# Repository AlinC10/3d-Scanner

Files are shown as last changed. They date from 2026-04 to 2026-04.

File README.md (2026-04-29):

# 3D Scanner Project

## How it started

This is a project created for the **Electrical Machines and Drives** university course. The main criteria for the project was to use an electrical motor.

## About the project

This is 3D scanning system built using an IR distance sensor and 2 stepper motors. The project transform the geometry of real objects into a Point Cloud and generates a 3D surface (Mesh), ready for 3D printing.

## Features

* **GUI**: An app written in Python (Tkinter library) with support for keyboard navigation, real-time log updates via Threading and automatic COM port management.
* **Automatic Surface Reconstruction**: Transform `.xyz` data into a 3d Model (`.obj`) using PyMeshLab
* **2-Axis Kinematics**: Control of the rotating turntable and the elevator using stepper motors and mechanical endstops.

[For information about software side of the project click here](./app_code/README.md)

## Hardware

### Bill of Materials

* **Microcontroller:** 1x Arduino Uno
* **Motors:** 2x 5V 28BYJ-48 Stepper Motors + Drivers
* **Sensor:** 1x Sharp GP2Y0A41SK0F (4-30 cm) IR sensor
* **Power Supply:** 1x 9v, 0.55A Power Supply (for motors)
* **Other Components for Arduino:**
  * 2x Mechanical Endstop (for bottom and upper parts of the threaded rod)
  * 1x Electrical Switch
  * Resistors (2x 100k, 10k)
  * Breadboard
* **Other components:**
  * 1x M8 Threaded Rod (for Z-axis)
  * 3x Hex Nuts
  * 2x Round Bars
  * 2x Low Pressure Ferrule
  * 1x Aluminium Flexible Coupling 5mm * 8mm (between motor's rod and M8 threaded rod)
  * Turntable (from a pick-up)
  * 2x Steel Flat Bar

### Components connections

* Sharp GP2Y0A41SK0F (4-30 cm) IR sensor: A0, GND, 5V
* Motors:
  * Turntable: 8-11 digital, breadboard +/-
  * Threaded Rod: 4-7 digital, breadboard +/-
* Mechanical Endstops:
  * Upper: from NO - breadboard - digital 3, breadboard -
  * Bottom: from NO - breadboard - digital 2, breadboard -
* Power Supply: + - breadboard + - voltage divider (110k, 100k) - digital 1, - to Electrical Switch to breadboard -

### [TinkerCad project design](https://www.tinkercad.com/things/5zCmhctaVLh-3d-scanner?sharecode=bmv8x4omlR0UC9AtyNq_ofs1a5cjaq0OV72FfIZm1b8)

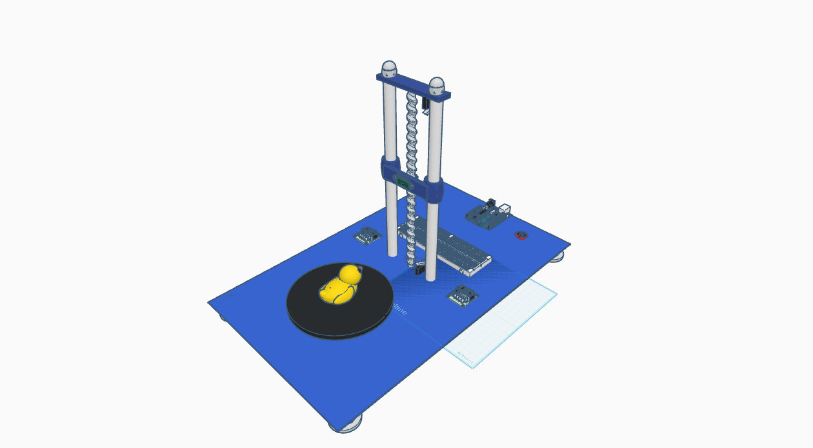
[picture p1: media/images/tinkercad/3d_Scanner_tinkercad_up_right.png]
3d scanner upper right

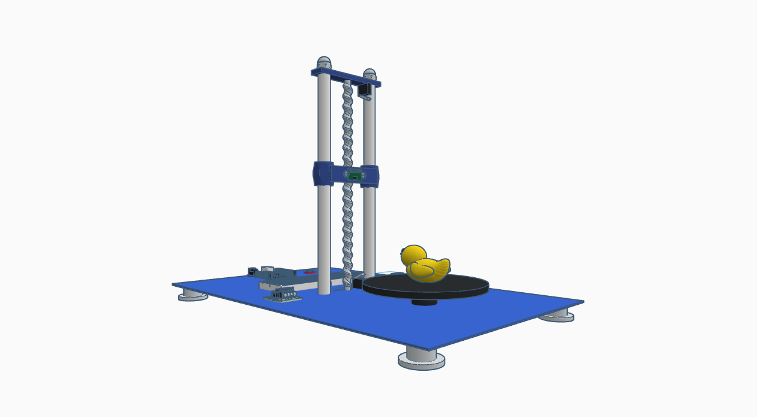
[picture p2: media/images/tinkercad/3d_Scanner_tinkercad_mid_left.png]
3d scanner mid left

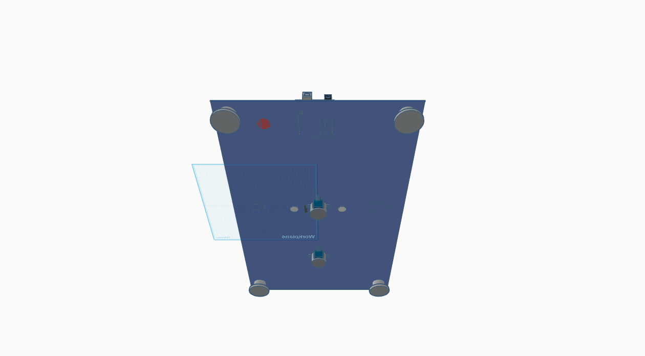
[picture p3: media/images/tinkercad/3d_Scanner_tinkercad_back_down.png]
3d scanner back down


### Real-life images of the scanner

### Future hardware updates

* change IR sensor with a camera and get coordinates from images
* change M8 rod with a T8 Threaded rod for faster movement on it

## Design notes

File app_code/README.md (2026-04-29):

# 3D Scanner Project

## Software

The logic of the system was implemented using C++ code (in Arduino IDE) and Python with multiple libraries.

*Note:* The GUI is currently in Romanian.

### Arduino

Arduino is responsible for how the scanner moves, scans the object and calculates the coordinates. The logic was created using OOP principles, creating different classes for different hardware components and handling their behavior inside the methods.

The classes created are:

* IR_Sensor:
  * getDistance(): was created using `SharpIR` library (by Giuseppe Masino) as a reference point. The problem with the already implemented one was that it only calculated the distance as an `int`, which was not useful for a system that tries to catch as many details as it can from an object. My implementation returns a `float` number, which represents the distance from the sensor to the object in millimeters. For a better value for the distance, the method makes multiple readings (10 by default) and returns the average distance.

* Endstop: checks if sensor reached bottom/upper part of the threaded rod
* Switch: checks if the power supply\switch is on
* Motor:
  * halfStepForward/Backwards(), fullStepForward/Backwards(): methods used to rotate motors forward/backwards in 2048 (with full step for threaded rod) or 4906 (with half step for turntable) depending on the needed precision.

Arduino code *only executes* if it receives a command from Python script, so it can't scan without Python script opened.

Variables used in the scanning process can be changed via Python script, in the `Opțiuni` menu from `Meniul Principal` without re-uploading the code (the settings changed will return to their values from Arduino code on the next launch) or via Arduino IDE (which means that the code needs to be re-uploaded).

### Python

The Python script acts as the "brain" of the operation on the PC side. It provides a Graphical User Interface (GUI), handles real-time communication with the microcontroller, and performs the complex 3D surface reconstruction. The entire logic is encapsulated in the ScannerApp class.

#### Features:
* **Serial Communication:** Utilizing the `pyserial` library (operating at a baud rate of `115200`), the script reads the incoming coordinates line by line and displays them in real-time. It also sends commands (START, STOP) and can dynamically update Arduino variables (like the number of measurements or sensor readings) without requiring the Arduino code to be recompiled or re-uploaded.
* **Data Management:** The raw coordinates are kept in memory and safely exported as an .xyz Point Cloud file. The script uses the pathlib library to automatically manage directories and save scans in dedicated folders based on user input.
* **Automated 3D Surface Reconstruction:** Once the scan is complete, the pymeshlab library is used to transform the raw .xyz points into a solid, 3D-printable .obj mesh

### How to run it

1. Setup Arduino

    1. Open `.\app_code\main\main.ino` in Arduino IDE.
    2. Check pins mapping for all hardware components.
    3. Upload code to Arduino.

2. Setup Python (3.11)
    1. Open terminal in `.\app_code\python`.
    2. Run `python -m venv .venv`
    3. Activate environment `.venv\Scripts\activate`
    4. Install libraries: `pip install -r requirements.txt`.
  
3. Install `MeshLab` to view the scanned object (optional, you can upload the `.xyz` in another app)

4. Connect Arduino, plug in the power supply and turn on the switch.

5. Run `3dScanner.exe` from `.\` or from terminal `python .\app_code\python\main.py`.

6. Press `Incepe scanarea` to start scanning.

7. After the scanning process, complete the name of the file in the pop-up window. For example, you can name the file `duck`, `my_favorite_duck`.

8. Click `Vizualizare obiect` to see the scanned object or choose `Meniu Principal` to go to the Main Menu. The file with scanned coordinates can be found in `.\scanari\your_object_name\your_object_name.xyz`.

### Future software updates

* create issues to better manage updates
* auto-search for arduino COM and baud-rate
* implement a ML algorithm to correct object coordinates
* migrate UI from Python Tkinter to a web based interface
* create a backend with python for sending information to the javascript frontend

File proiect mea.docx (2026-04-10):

Perfectă decizie! Trecerea de la un CD la o placă din MDF (de 6 mm sau 8 mm grosime) sau o foaie de plastic rigid va face scannerul mult mai stabil, va elimina vibrațiile și îți va permite să scanezi obiecte mai grele.

Pentru a-ți face viața mai ușoară, am împărțit "coșul de cumpărături" în două categorii: ce iei de la magazinele de electronică (cum ar fi Optimus Digital, Clește.ro, RoboFun etc.) și ce iei de la magazinele de bricolaj (Dedeman, Hornbach, Leroy Merlin).

Presupun că ai deja placa Arduino Uno și cablul USB.

1. Electronice (Magazine de specialitate / Roboți)

- 1x Senzor de distanță ToF VL53L0X (~25 - 35 RON).
- 2x Motoare pas cu pas 28BYJ-48 (5V) cu driver ULN2003 (~15 RON bucata -> 30 RON total). Atenție să iei varianta de 5V, nu cea de 12V.
- 1x Set fire Dupont (Tată-Mamă și Mamă-Mamă) (~10 RON). Ai nevoie de ele pentru a conecta pinii plăcuțelor direct la Arduino și între ele.
- 1x Breadboard (placă de teste) mic sau mediu (~10 RON). Te va ajuta enorm să distribui alimentarea de 5V către ambele motoare și senzor.
- 1x Microîntrerupător (Limitator de cursă / Endstop) (~3 - 5 RON). Un buton mic pe care îl vei pune la baza tijei pentru a-i spune senzorului unde este punctul "zero".
- (Opțional, dar recomandat) 1x Cuplaj flexibil aluminiu (5mm la 5mm sau 5mm la 6mm) (~15 RON). Te va ajuta să prinzi perfect axul motorului de tija filetată. Axul motorului 28BYJ-48 are 5mm. Dacă iei o tijă filetată de 5mm, iei cuplaj 5mm-5mm.

Total estimat electronice: ~80 - 95 RON

2. Mecanică și Bricolaj (Dedeman / Hornbach etc.)

- 1x Tijă filetată M5 sau M6 (~5 - 10 RON). Se vinde la bucăți de 1 metru. (M5 înseamnă grosime de 5 mm).
- 1x Pungă mică piulițe (M5 sau M6, în funcție de tijă) + șaibe (~5 RON).
- 1x Tijă netedă pentru ghidaj (țeavă subțire de aluminiu sau oțel neted de 6mm sau 8mm) (~10 RON). Tot la profilul de 1 metru o găsești. Trebuie să fie perfect dreaptă.
- 1x Placă MDF (grosime 6mm sau 8mm) (~15 - 20 RON). De obicei găsești resturi sau plăci mici (ex: 60x60 cm). Din ea vei tăia baza, peretele vertical (în forma de "L") și vei decupa cercul pentru platan.
- 1x Set colțare metalice mici (în formă de L) + holzșuruburi scurte (~10 RON). Pentru a prinde peretele vertical de baza orizontală la un unghi perfect de 90 de grade.
- (Opțional) Bile de transfer (Role / Rulmenți de mobilă mici) (~15 RON). Le prinzi pe bază, sub platanul de MDF, ca platanul să alunece pe ele. Asta ia toată greutatea de pe axul firav al motorului.

Total estimat bricolaj: ~60 - 70 RON

Sursa de alimentare (Improvizație acasă)

Pentru a alimenta motoarele, NU folosi portul USB de la PC prin Arduino. Caută prin casă un încărcător vechi de telefon care nu îți mai trebuie (dar să aibă minim 1.5 Amperi sau 2A scriși pe el). Îi vei tăia mufa, vei dezizola firele roșu (+) și negru (-) și le vei folosi pentru a aduce curent pe breadboard.

Cost total estimat al proiectului: Undeva la 150 RON, dar vei avea un scanner stabil, de o calitate mult superioară variantelor din carton sau cu senzor ultrasonic.

Ai prefera ca următorul pas să fie realizarea schemei de conectare (cum legăm firele între componente și Arduino) sau vrei să începem să scriem codul de bază pentru teste?

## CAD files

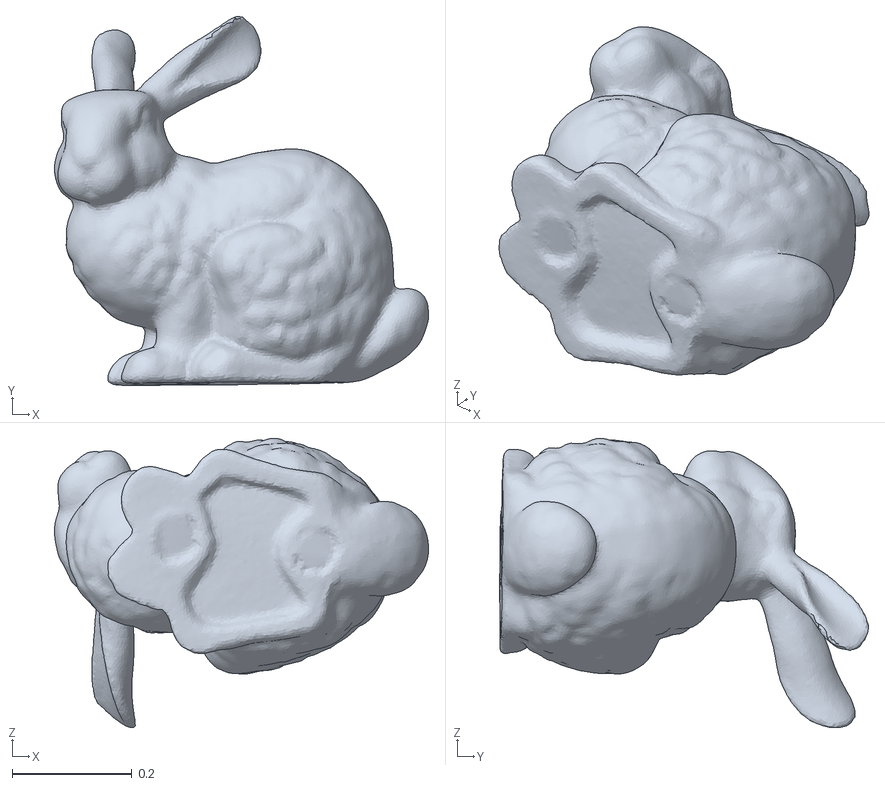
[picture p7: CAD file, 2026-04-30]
3d_Scanner_app/_internal/pymeshlab/tests/sample_meshes/bunny.obj
0.624 x 0.615 x 0.482

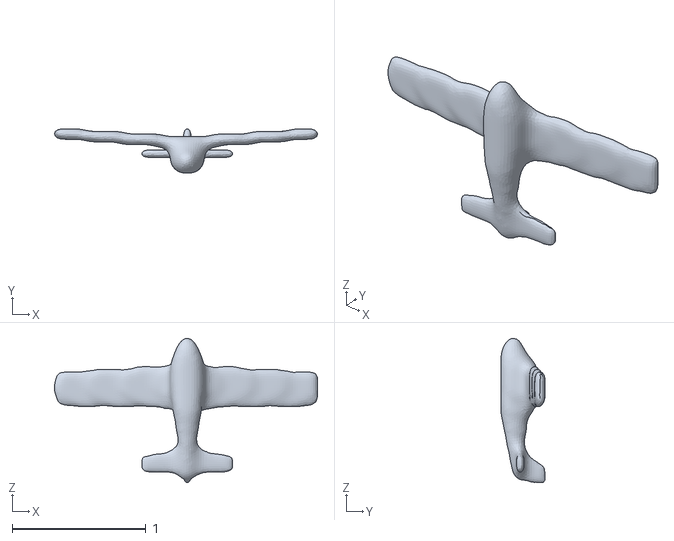
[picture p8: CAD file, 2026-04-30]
3d_Scanner_app/_internal/pymeshlab/tests/sample_meshes/colored_airplane.ply
1.96 x 0.331 x 1.08

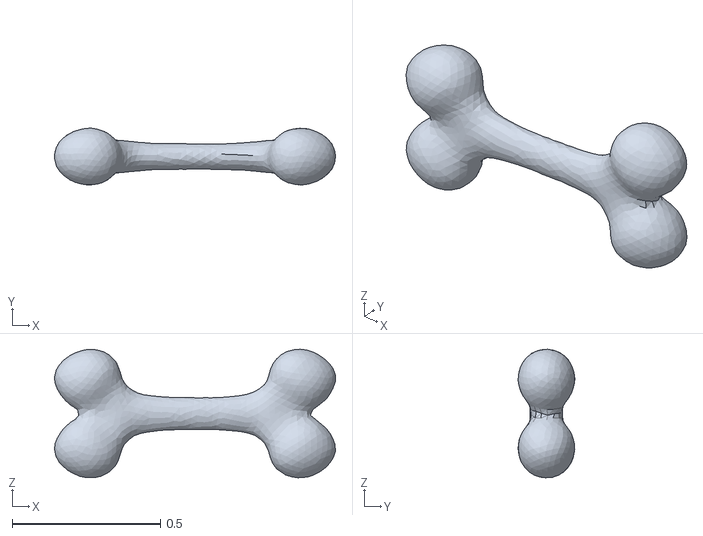
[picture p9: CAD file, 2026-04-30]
3d_Scanner_app/_internal/pymeshlab/tests/sample_meshes/bone.ply
0.949 x 0.192 x 0.435

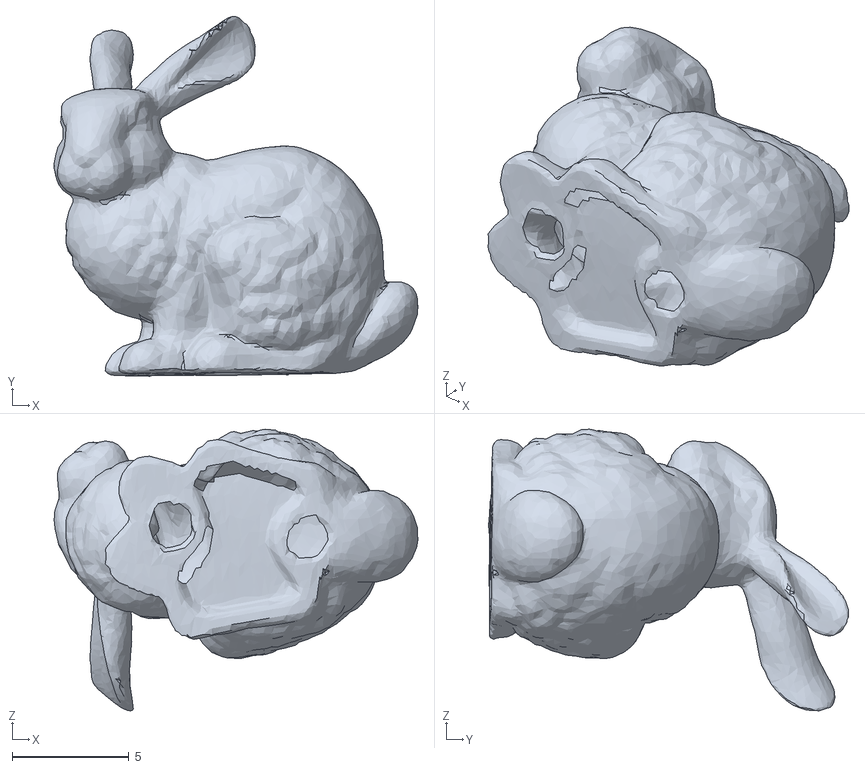
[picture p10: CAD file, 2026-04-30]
3d_Scanner_app/_internal/pymeshlab/tests/sample_meshes/bunny10k_textured.obj
15.6 x 15.4 x 12.1

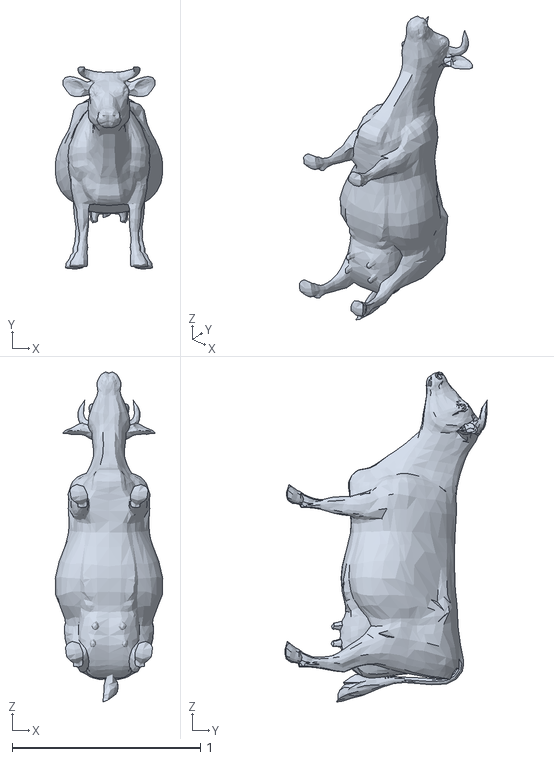
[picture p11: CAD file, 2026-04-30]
3d_Scanner_app/_internal/pymeshlab/tests/sample_meshes/cow.obj
0.572 x 1.08 x 1.76

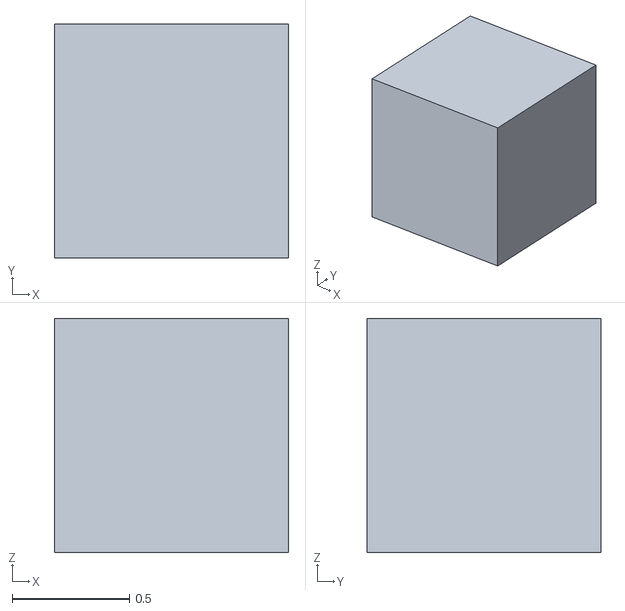
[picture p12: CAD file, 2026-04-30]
3d_Scanner_app/_internal/pymeshlab/tests/sample_meshes/cube.obj
1.00 x 1.00 x 1.00

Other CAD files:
3d_Scanner_app/_internal/pymeshlab/tests/sample_meshes/airplane.obj

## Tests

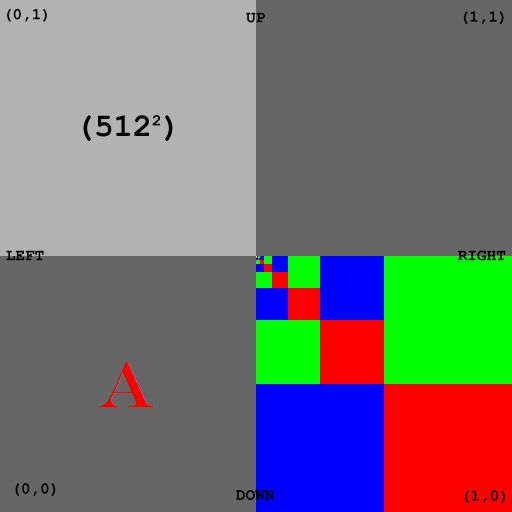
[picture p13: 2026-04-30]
3d_Scanner_app/_internal/pymeshlab/tests/sample_meshes/TextureDouble_A.png

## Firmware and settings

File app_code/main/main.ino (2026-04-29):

#include "motor.h"
#include "endstop.h"
#include "switch.h"
#include "IR_Senzor.h"
#include "scanner_functions.h"
#include <Wire.h>

#define M8_THREAD_STEP_MM 1.25
#define DISTANCE_TO_CENTER_MM 110.0
#define DISTANCE_TO_END_MM 240.0

Motor zMotor(Z_MOTOR_OUTPUT1, Z_MOTOR_OUTPUT2, Z_MOTOR_OUTPUT3, Z_MOTOR_OUTPUT4, ROTATION_STEPS_Z_MOTOR);
Motor turntableMotor(TURNTABLE_MOTOR_OUTPUT1, TURNTABLE_MOTOR_OUTPUT2, TURNTABLE_MOTOR_OUTPUT3, TURNTABLE_MOTOR_OUTPUT4, ROTATION_STEPS_TURNTABLE_MOTOR);

Endstop upperEndstop(UPPER_ENDSTOP_INPUT);
Endstop bottomEndstop(BOTTOM_ENDSTOP_INPUT);

Switch chargerSwitch(SWITCH_PIN);

IR_Senzor sensor(SENZOR_PIN);
long currentLevel = 0;

void setup() {
  Serial.begin(115200);

  // setup components pin
  zMotor.pinSetup();
  turntableMotor.pinSetup();

  upperEndstop.pinSetup();
  bottomEndstop.pinSetup();

  chargerSwitch.pinSetup();
}

void setupScanner() {
  Serial << "Start\n";

  if (!chargerSwitch.isOn()) {
    Serial << "Alimentare motoare oprita\n";

    // wait to turn on charger
    while (!chargerSwitch.isOn()) {
      delay(5000);
    }
  }

  if (!bottomEndstop.reachRodLimit()) {
    Serial << "Se ajusteaza inaltimea senzorului\n";

    // get IR sensor at the bottom of the threaded rod
    while (!bottomEndstop.reachRodLimit()) {
      zMotor.fullStepBackward();
    }
  }

    delay(500);

  for (int j = 0; j < zMotor.getRotationSteps(); j++) {
    zMotor.fullStepForward();
  }

  zMotor.stop();
  delay(2000);
}

void scanning() {
  while (true) {
    // variable used to automate stop scanner in case it finished object scanning
    bool hasScanned = false;

    Serial << "\n\nNivelul curent: " << currentLevel << "\n";

    if (checkStoppingConditions(upperEndstop.reachRodLimit(), zMotor, turntableMotor))
      return;

    const int stepsBetweenMeasurements = turntableMotor.stepsBetweenMeasurements();

    for (int i = 0; i < MEASUREMENTS_PER_ROTATION; i++) {

      for (int j = 0; j < stepsBetweenMeasurements / 8; j++) {
        turntableMotor.halfStepForward();
      }

      if (checkStoppingConditions(upperEndstop.reachRodLimit(), zMotor, turntableMotor))
        return;

      delay(100);

      float const distance = sensor.getDistance();

      turntableMotor.stop();
      if (distance > 40.0 && distance < DISTANCE_TO_CENTER_MM) {
        const float objRadius = DISTANCE_TO_CENTER_MM - distance;

        if (objRadius > 2.0) {
          float currentAngle = (360.0 / MEASUREMENTS_PER_ROTATION) * i;
          currentAngle *= (PI / 180.0);

          const float xPos = objRadius * cos(currentAngle);
          const float yPos = objRadius * sin(currentAngle);
          // const float zPos = (currentLevel * zMotor.getRotationSteps() / 2 * 4.0 * M8_THREAD_STEP_MM) / zMotor.getRotationSteps();
          const float zPos = currentLevel * 2 * M8_THREAD_STEP_MM;  // reduced form
          Serial << xPos << " " << yPos << " " << zPos << "\n";

          // create object base surface
          if (currentLevel == 0) {
            Serial << xPos * 0.75 << " " << yPos * 0.75 << " 0.0\n";
            Serial << xPos * 0.50 << " " << yPos * 0.50 << " 0.0\n";
            Serial << xPos * 0.25 << " " << yPos * 0.25 << " 0.0\n";
            Serial << "0.0 0.0 0.0\n";
          }

          hasScanned = true;
        }
      }
    }

    for (int j = 0; j < zMotor.getRotationSteps() / 2; j++) {
      if (checkStoppingConditions(upperEndstop.reachRodLimit(), zMotor, turntableMotor))
        return;
      zMotor.fullStepForward();
    }
    currentLevel++;
    zMotor.stop();

    if (checkStoppingConditions(!hasScanned, zMotor, turntableMotor))
      return;
  }
}

void readSerial() {
  // wait for user to select start scanning option
  // answer it's received by python and send through the serial to arduino
  if (Serial.available() > 0) {
    const String pythonCommand = Serial.readStringUntil("\n");
    pythonCommand.trim();

    // start scanning
    if (pythonCommand == "START") {
      setupScanner();
      scanning();
    }

    // command to stop scanning
    else if (pythonCommand == "STOP") {
      return;
    }

    // command to change variables values
    else {
      const int separatorIndex = pythonCommand.indexOf(":");

      if(separatorIndex != -1) {
        const String varName = pythonCommand.substring(0, separatorIndex);

        const int varValue = pythonCommand.substring(separatorIndex + 1).toInt();

        if (varName == "MEASSUREMENTS")
          MEASUREMENTS_PER_ROTATION = varValue;

        if (varName == "READINGS")
          readings = varValue;
      }
    }
  }
}

// run loop while arduino is turn on
void loop() {
  readSerial();
  delay(1000);
}

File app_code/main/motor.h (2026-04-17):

#pragma once
#include "Arduino.h"

#define Z_MOTOR_OUTPUT1 7
#define Z_MOTOR_OUTPUT2 6
#define Z_MOTOR_OUTPUT3 5
#define Z_MOTOR_OUTPUT4 4
#define ROTATION_STEPS_Z_MOTOR 2048

#define TURNTABLE_MOTOR_OUTPUT1 11
#define TURNTABLE_MOTOR_OUTPUT2 10
#define TURNTABLE_MOTOR_OUTPUT3 9
#define TURNTABLE_MOTOR_OUTPUT4 8
#define ROTATION_STEPS_TURNTABLE_MOTOR 4096

int MEASUREMENTS_PER_ROTATION = 64; // can be change by user through python script

class Motor {
private:
  int output1;
  int output2;
  int output3;
  int output4;
  int rotationSteps; // how many steps it take on a rotation
  static const int DELAY = 2;

public:
  Motor(int output1, int output2, int output3, int output4, int rotationSteps) {
    this->output1 = output1;
    this->output2 = output2;
    this->output3 = output3;
    this->output4 = output4;
    this->rotationSteps = rotationSteps;
  }

  void pinSetup() {
    pinMode(this->output1, OUTPUT);
    pinMode(this->output2, OUTPUT);
    pinMode(this->output3, OUTPUT);
    pinMode(this->output4, OUTPUT);
  }

  int stepsBetweenMeasurements() {
    return this->rotationSteps / MEASUREMENTS_PER_ROTATION;
  }

  int getRotationSteps() const {
    return this->rotationSteps;
  }

  void fullStepRotation(int output1, int output2, int output3, int output4) {
    digitalWrite(output1, HIGH);
    digitalWrite(output2, HIGH);
    digitalWrite(output3, LOW);
    digitalWrite(output4, LOW);
    delay(DELAY);
  }

  void halfStepRotation(int output1, int output2, int output3, int output4) {
    digitalWrite(output1, HIGH);
    digitalWrite(output2, LOW);
    digitalWrite(output3, LOW);
    digitalWrite(output4, LOW);
    delay(DELAY);
  }

  void fullStepForward() {
    this->fullStepRotation(this->output1, this->output2, this->output3, this->output4);
    this->fullStepRotation(this->output2, this->output3, this->output1, this->output4);
    this->fullStepRotation(this->output3, this->output4, this->output1, this->output2);
    this->fullStepRotation(this->output1, this->output4, this->output2, this->output3);
  }

  void fullStepBackward() {
    this->fullStepRotation(this->output3, this->output4, this->output1, this->output2);
    this->fullStepRotation(this->output2, this->output3, this->output1, this->output4);
    this->fullStepRotation(this->output1, this->output2, this->output3, this->output4);
    this->fullStepRotation(this->output1, this->output4, this->output2, this->output3);
  }

  void halfStepForward() {
    this->halfStepRotation(this->output1, this->output2, this->output3, this->output4);
    this->fullStepRotation(this->output1, this->output2, this->output3, this->output4);
    this->halfStepRotation(this->output2, this->output1, this->output3, this->output4);
    this->fullStepRotation(this->output2, this->output3, this->output1, this->output4);
    this->halfStepRotation(this->output3, this->output1, this->output2, this->output4);
    this->fullStepRotation(this->output3, this->output4, this->output1, this->output2);
    this->halfStepRotation(this->output4, this->output1, this->output2, this->output3);
    this->fullStepRotation(this->output1, this->output4, this->output2, this->output3);
  }

  void halfStepBackward() {
    this->halfStepRotation(this->output4, this->output1, this->output2, this->output3);
    this->fullStepRotation(this->output3, this->output4, this->output1, this->output2);
    this->halfStepRotation(this->output3, this->output1, this->output2, this->output4);
    this->fullStepRotation(this->output2, this->output3, this->output1, this->output4);
    this->halfStepRotation(this->output2, this->output1, this->output3, this->output4);
    this->fullStepRotation(this->output1, this->output2, this->output3, this->output4);
    this->halfStepRotation(this->output1, this->output2, this->output3, this->output4);
    this->fullStepRotation(this->output1, this->output4, this->output2, this->output3);
  }

  void stop() {
    digitalWrite(this->output1, LOW);
    digitalWrite(this->output2, LOW);
    digitalWrite(this->output3, LOW);
    digitalWrite(this->output4, LOW);
  }
};

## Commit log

2026-04-10 adaugat cod de test motoare, link tinkercad
2026-04-12 implementat logica scanner ului
    - am implementat logica scanner ului in arduino, folosindu-ma de 3 clase pentru a controla obiectele scanner ului mai usor
    - am creat un script python care sa ia coordonatele transmise de la arduino si sa le salveze intr-un fisier "./cod proiect/dist/coords.xyz"
    - am creat un executabil pentru script ul de python care se afla la "./cod proiect/dist/script.exe" pentru a vizualiza ce se intampla cu scanner ul in timp real
2026-04-15 change sensor
2026-04-17 features for next test
    - add new header with function related with sensor
    - modify main.ino to receive a signal from python when the scanner should start
    - modify main.ino to work in an infinite loop
2026-04-25 fixed bugs and modified UI
    - modify IR sensor distance formula with a better version from <Sharp.h> transformed for float variables for better coordinates calculus
    - merge changes from gui-branch into main branch
    - apply new filters to the MeshLab object to add a horizontal cover for the base of the object
    - create options menu in the UI, for controlling how the sensor will perform
    - modify how files are created. Now, they will be added in a directory with the chosen name
    [ScannerApp.py, main.ino]
2026-04-29 fix sensor distance calculation
    - update distance formula based on the SharpIR library
    - rename directories and reorganize file structure
    - update save path for scanned coordinates
    - add README documentation
    - add explanatory comments to the Python script
    [ScannerApp.py, main.ino, motor.h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]
2026-04-30 implement automatic serial port finder
    - create a function that check all ports to find Arduino com
    - update requirements.txt
    - create a .exe for the Python script
    [airplane.obj, bone.ply, bunny.obj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]
